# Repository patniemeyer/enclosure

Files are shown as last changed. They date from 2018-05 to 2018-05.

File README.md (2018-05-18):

# Simple OpenSCAD Press-fit Acrylic Printer Enclosure
_Pat Niemeyer (pat@pat.net), https://github.com/patniemeyer/enclosure_

<table>
  <tr>
    <th>
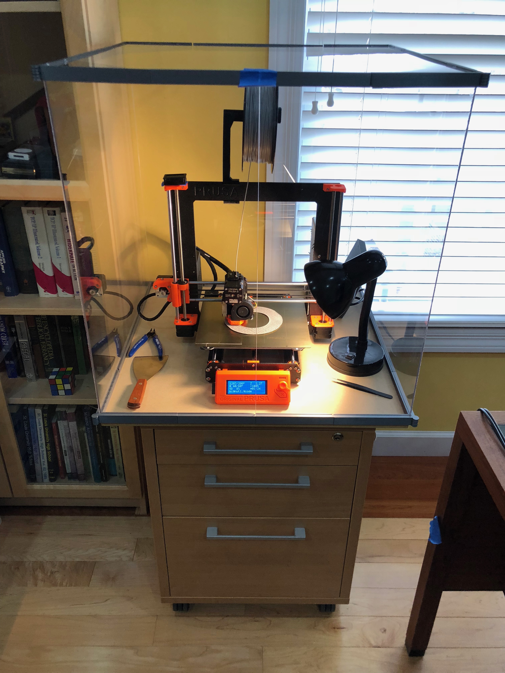
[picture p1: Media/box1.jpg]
      
    </th>
    <th>
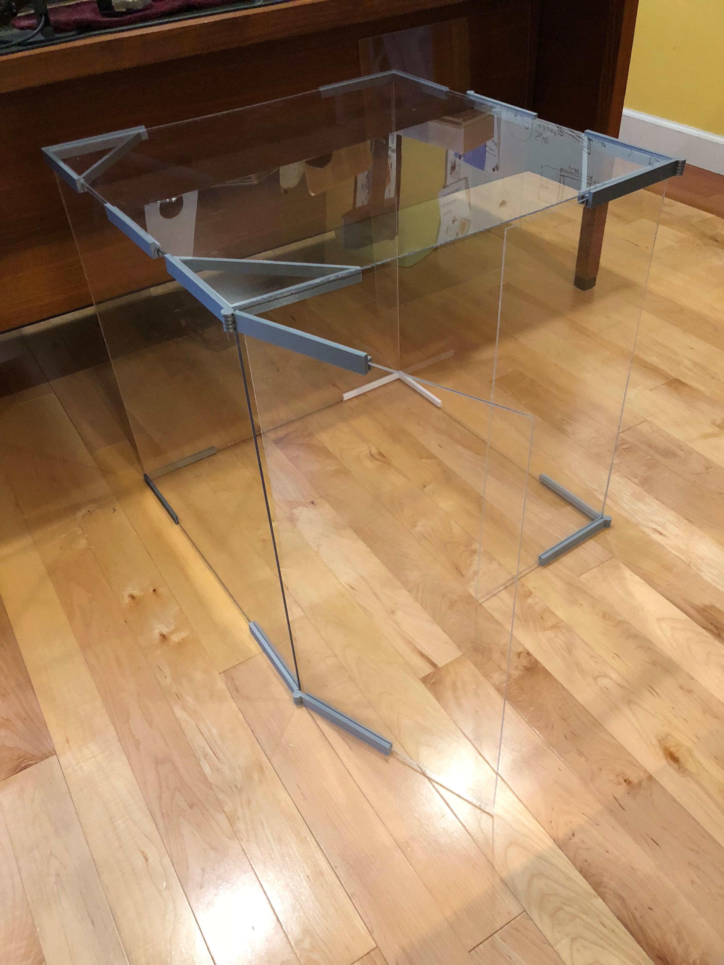
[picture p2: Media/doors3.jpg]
      
    </th>
    <th>
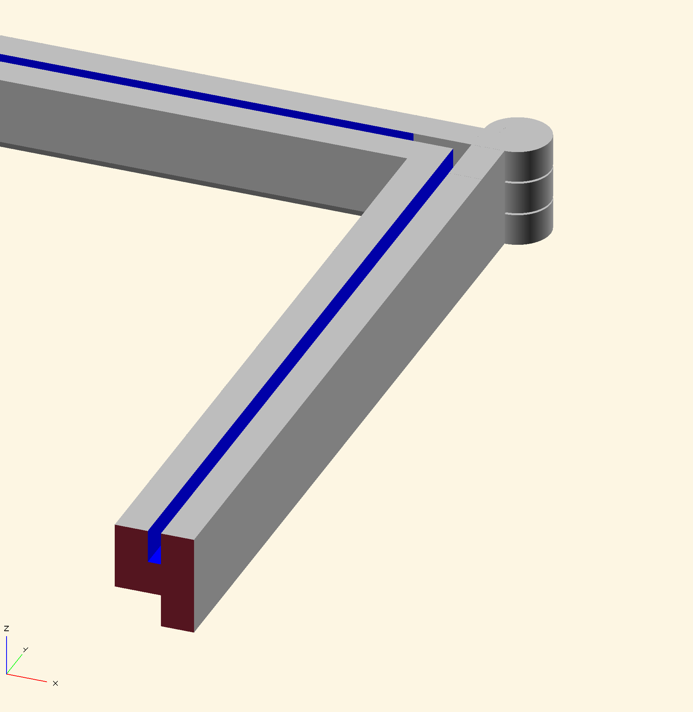
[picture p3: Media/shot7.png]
    
    </th>
  </tr>
</table>

This is my attempt at a simple, customizable press-fit printer enclosure that works with cheap (2.5mm or 3mm) acrylic and looks nice. The gihub project contains the OpenSCAD files that can be customized for any material thickness and box dimensions. Although I iterated on this a bit when I was building mine, I’d still consider this experimental so please read the notes below on what worked well and what didn’t.  I’m satisfied with the results and if I ever have another need for a giant acrylic box I’ll refine it more!

## Goals and room for improvement

* Use cheap acrylic:  1/4” acrylic is expensive.   You can get 3 sheets of 24x48” 3mm acrylic at Menard’s for less than $100 (you only really needed 2.5 of those for 5 panels). 

* Press-fit:  I did not want to have to drill or glue.  Other than getting 24” x 24” acrylic and cutting one in half for the doors I wanted to be able to press it together and perhaps take it apart when not needed.  In practice, the press-fit worked for some pieces but ended up a bit loose on others.  Ultimately I ended up putting a few spots of hot glue on strategic points to keep it from sliding.

* Base or no base:  The design incorporates a 24” x 24” base, but this can be removed (turned off in the scad file) for the bottom pieces if you prefer it to sit flush on a table.  Home Depot has 3/4” MDF square boards that are exactly 24” on a side for about $5. Sitting on a base allows the outside hinges to open the doors more freely.   If you use the base you may need to secure it since it doesn’t have much horizontal support in the front and could tend to slide off.

* Simple parts: Ideally it would use just three types of parts: straight edges, corner pieces, and hinged corner pieces.  In practice the thin acrylic slumped a bit on the “roof”, which made it harder to close the doors and in an attempt to fix this I adding the corner braces.  Unfotunately this means that there are now left and right hinges for the doors.   (Note: If you don’t care about the enclosure being air tight you don’t need the straight pieces!)

## Printing the parts 

The STL folder contains rendered models for a 24"x24" box with 0.118" / 3.0mm acrylic, but the scad files are easily adapted for any size and thickness.  If there is any interest in the project I will expand the pre-rendered selection and add instructions for options that can be customized. For now you'll just have to look at the source or ask me.

It does take a while to print the parts, but only the hinges require much detail.  I printed the straight and corner pieces at 0.2 or 0.35mm and the hinges at 0.1mm on my Prusa MK3.  The 12” straight pieces will fit if turned diagonally.

## Cutting Acrylic (if you have to) 
If you end up like me buying 48” sheets of acrylic you’ll need to cut them somehow.  I bought a 200 tooth table saw blade for $10 and it worked, but the results were a bit pitted.  Be sure to keep the plastic coating on the acrylic until you are finished cutting (or put blue painters tape on to protect if if you have exposed sheets).

## Ventilation 
I ended up placing mine on a table that it slightly smaller than the 24” base, allowing me to put a fan vent hole in the bottom.  In practice a 40mm fan can suck out enough air that it doesn’t really matter where it is.  I’m planning to vent it to a window later.

## Quiet!
Almost any kind of box that seals reasonbly well will dramatically reduce the sound of your printer- especially the high frequency whine of fans.  So yes, this does work well to reduce noise.

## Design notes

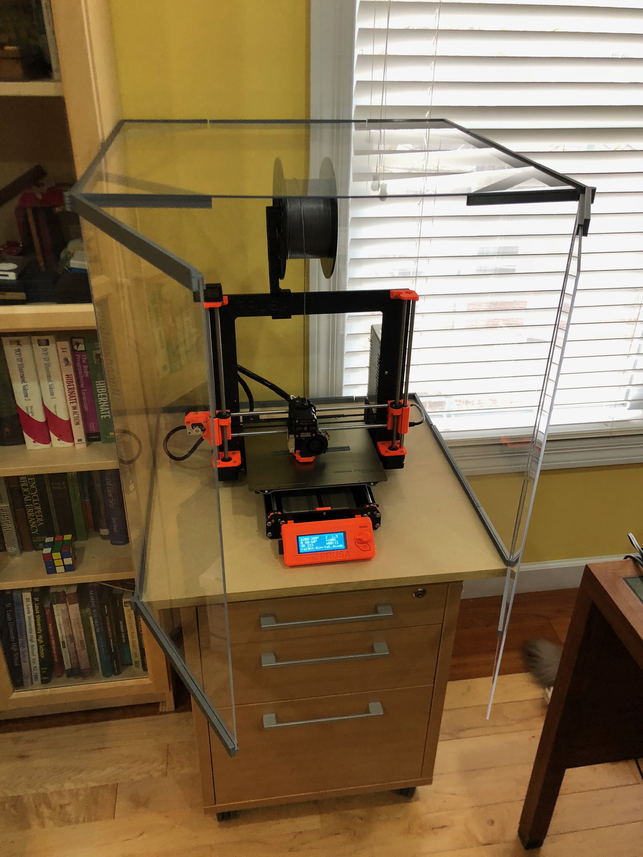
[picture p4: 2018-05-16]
Media/box2.jpg

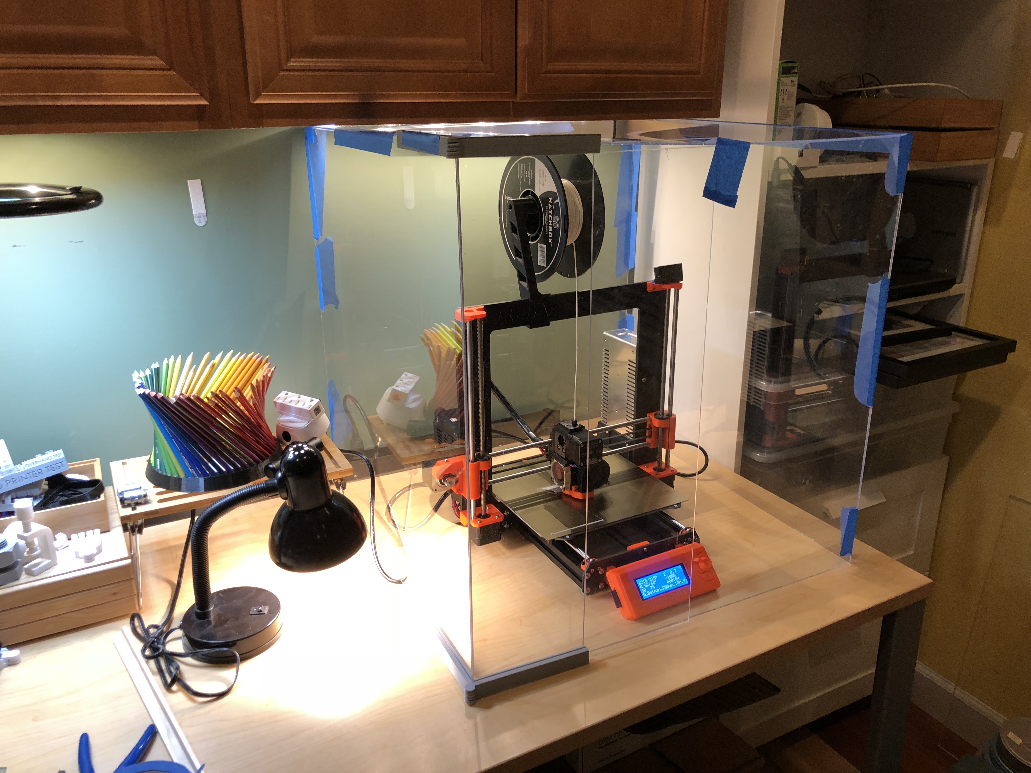
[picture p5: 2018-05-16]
Media/box3.jpg

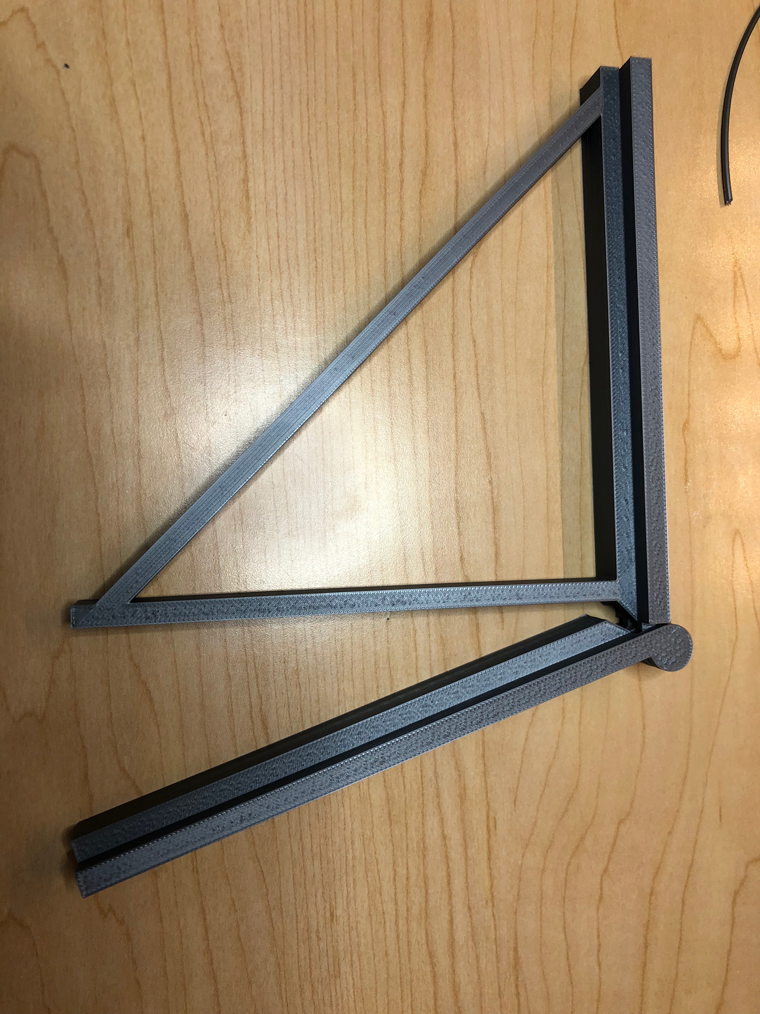
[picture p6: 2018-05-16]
Media/hinge3.jpg

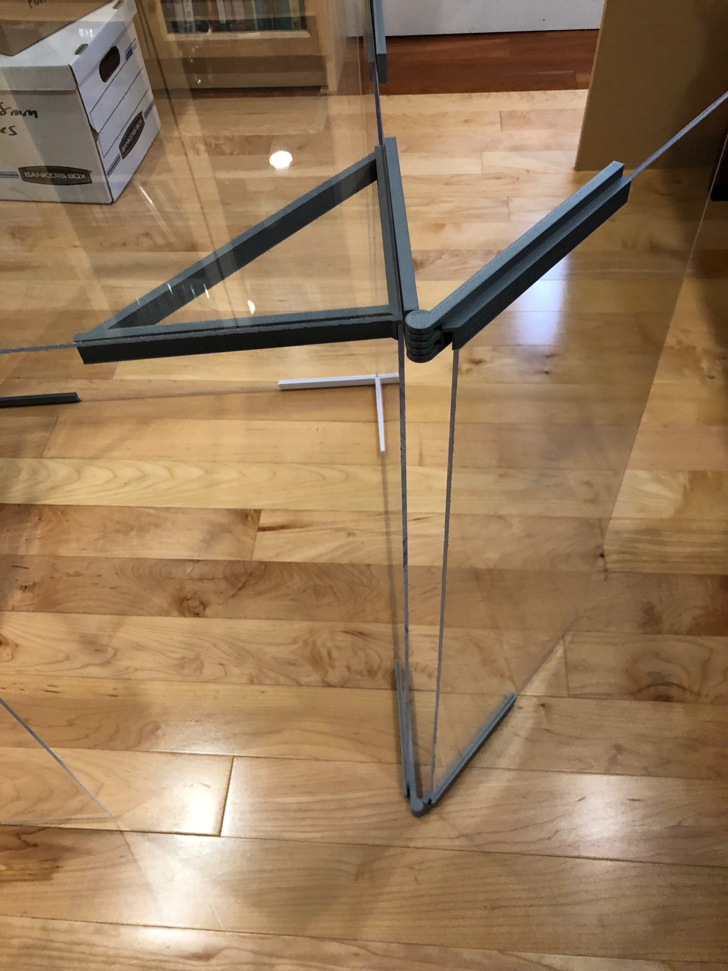
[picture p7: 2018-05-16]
Media/doors1.jpg

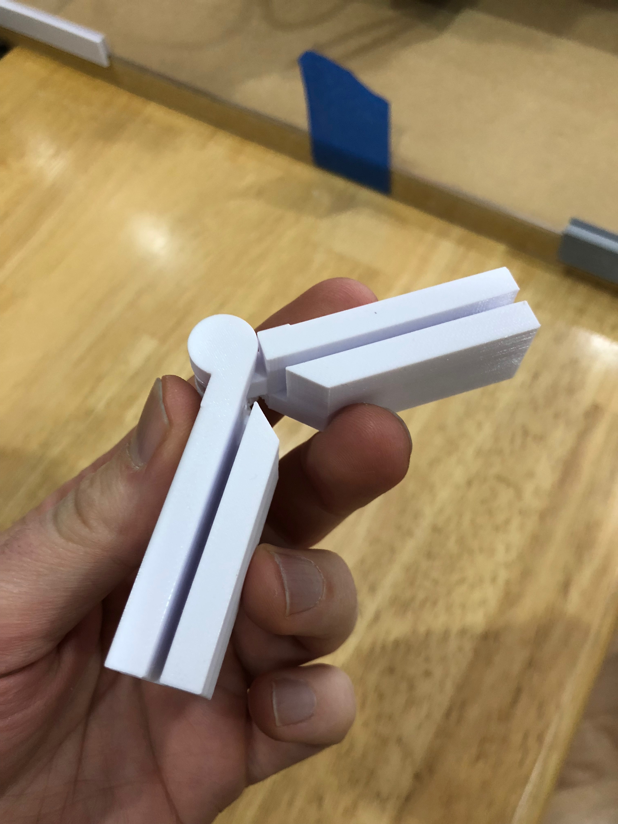
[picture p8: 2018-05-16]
Media/hinge2.jpg

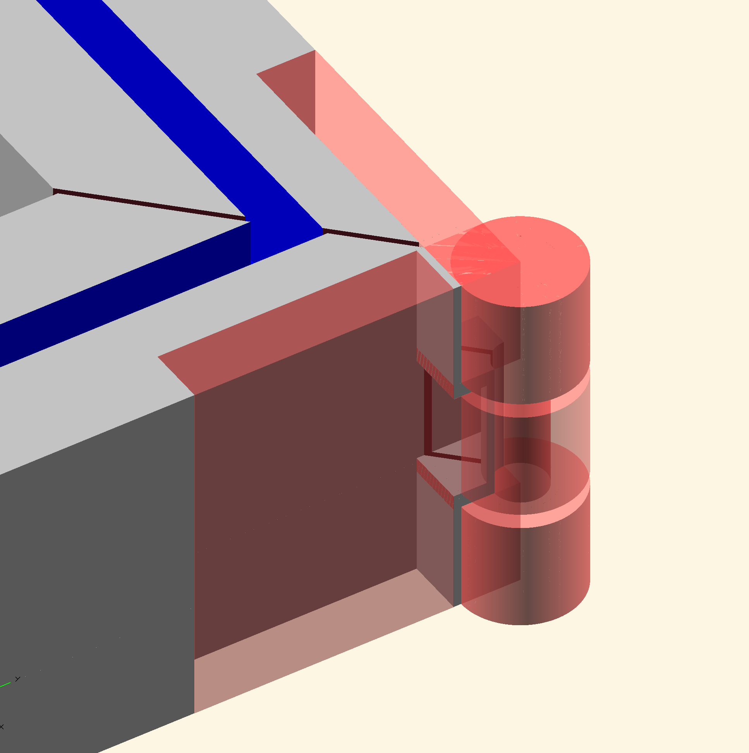
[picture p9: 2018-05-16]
Media/shot3.png

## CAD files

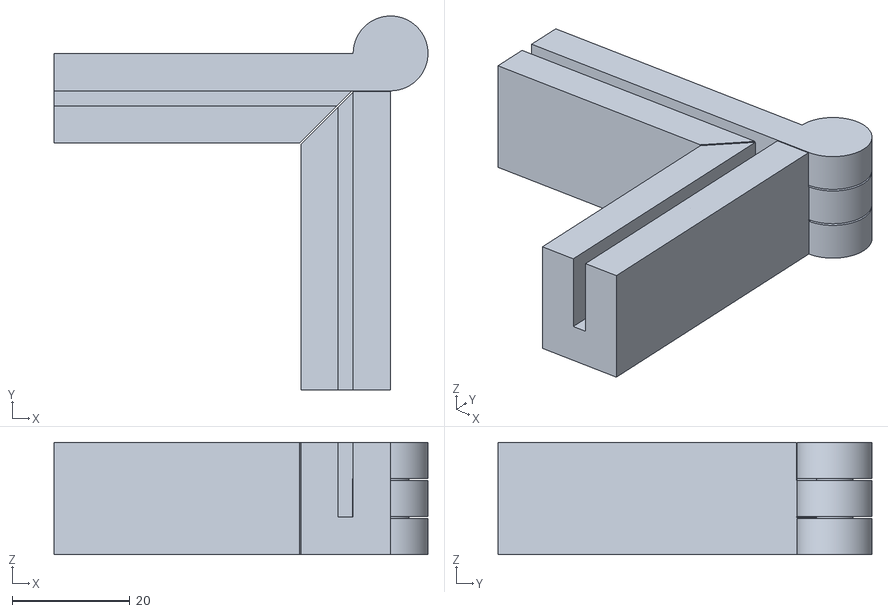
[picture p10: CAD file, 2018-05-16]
ExperimentsSTL/printer-enclosure6.stl
63.5 x 63.5 x 19.1

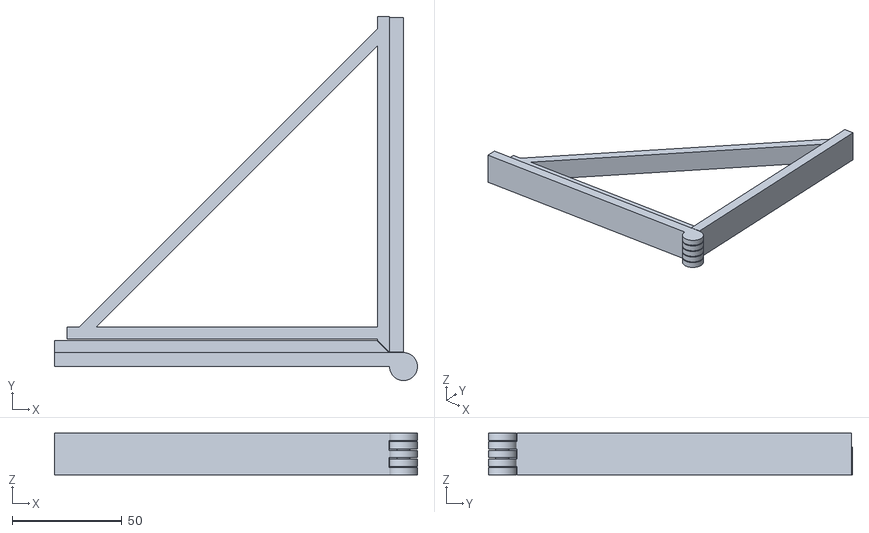
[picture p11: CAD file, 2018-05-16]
STL/corner-hinge-brace-right-6in.stl
165.1 x 165.6 x 19.1

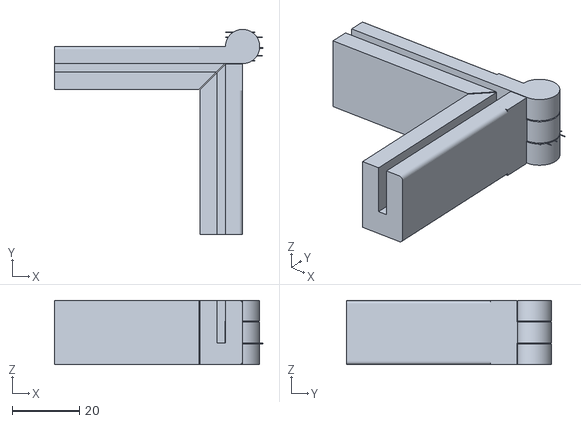
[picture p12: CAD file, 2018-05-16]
ExperimentsSTL/printer-enclosure10.stl
61.8 x 61.0 x 19.1

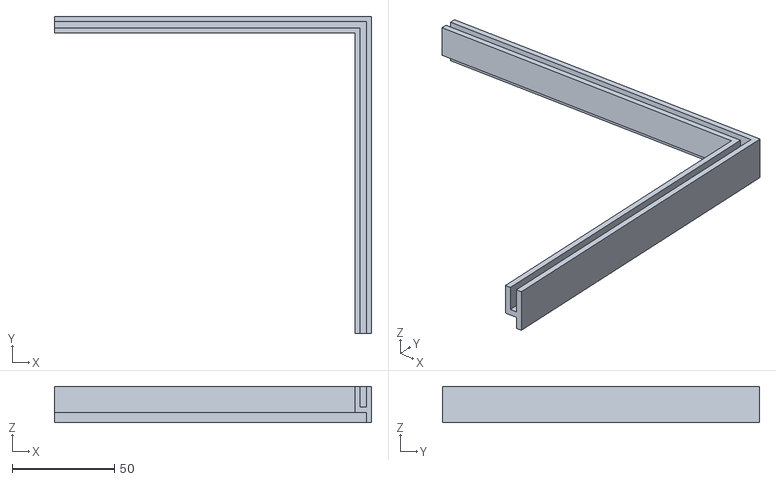
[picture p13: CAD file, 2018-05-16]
STL/corner-6in.stl
154.9 x 154.9 x 17.8

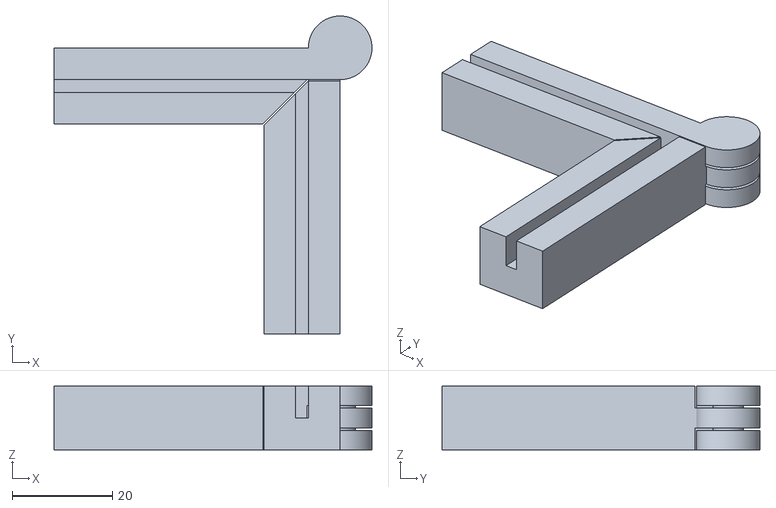
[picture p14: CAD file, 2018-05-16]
ExperimentsSTL/printer-enclosure.stl
63.5 x 63.5 x 12.7

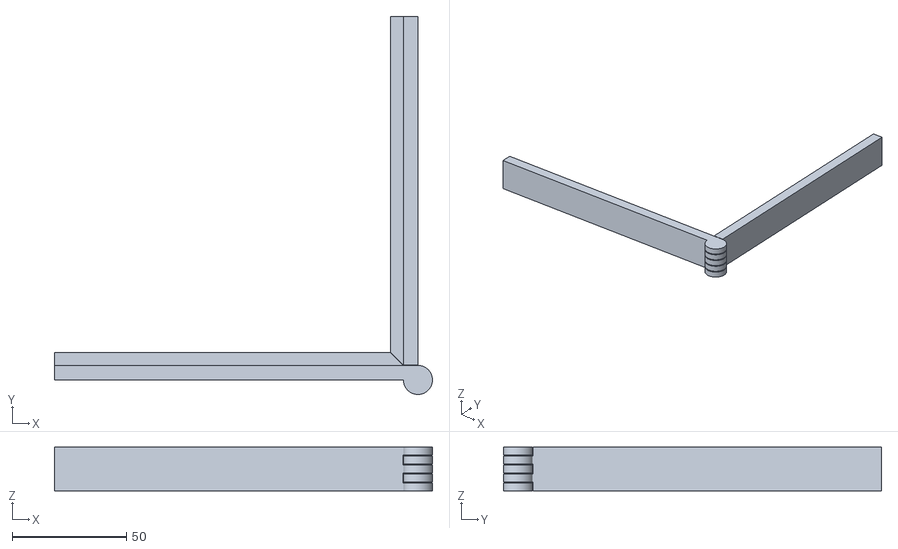
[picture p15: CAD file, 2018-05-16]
STL/corner-hinge-6in.stl
165.1 x 165.1 x 19.1

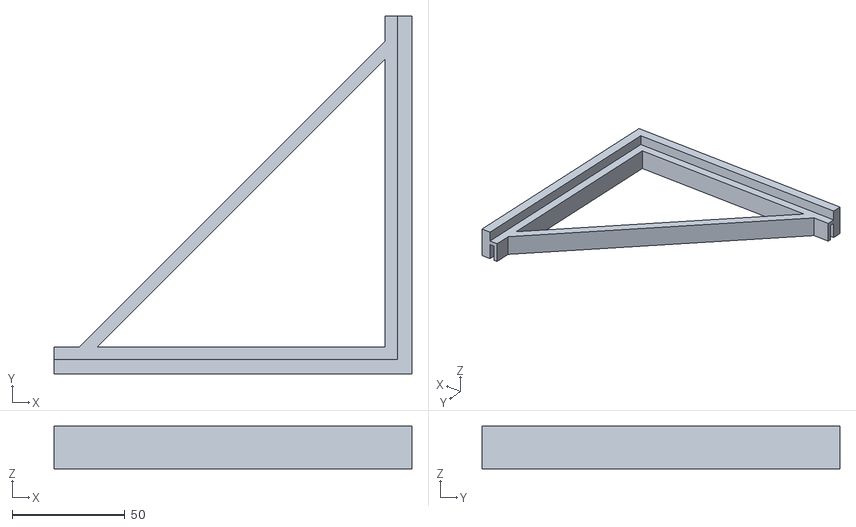
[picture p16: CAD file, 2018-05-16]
STL/corner-brace-6in.stl
158.8 x 158.8 x 19.0

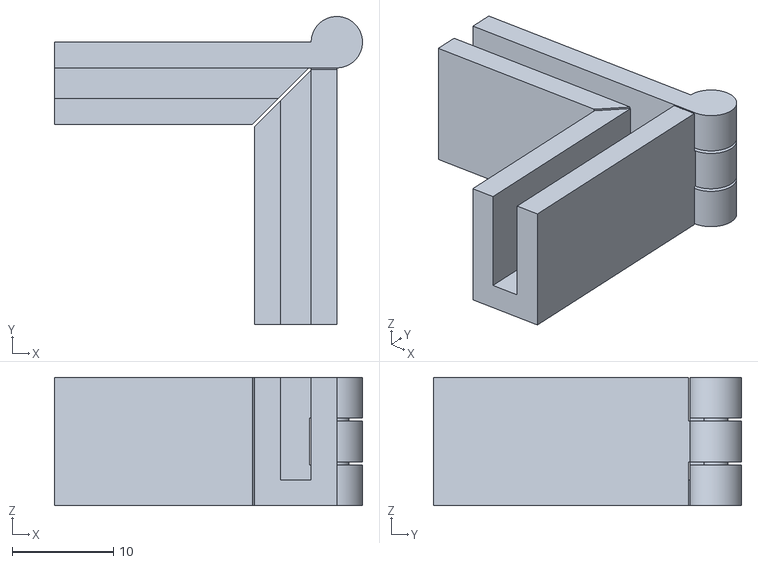
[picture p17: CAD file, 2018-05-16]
ExperimentsSTL/hingbottom1.stl
30.5 x 30.5 x 12.7

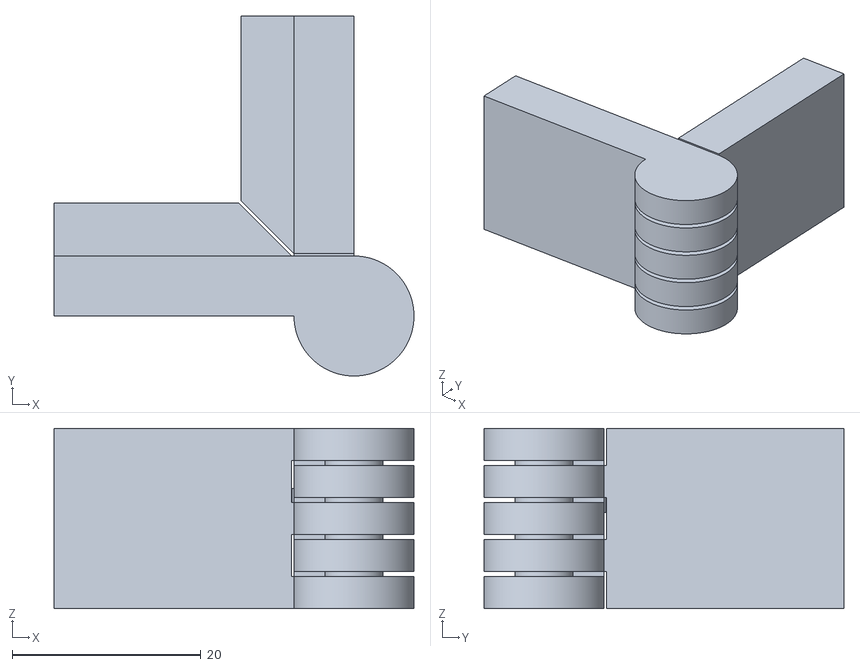
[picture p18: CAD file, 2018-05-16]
STL/corner-hinge-test-1in.stl
38.1 x 38.1 x 19.1

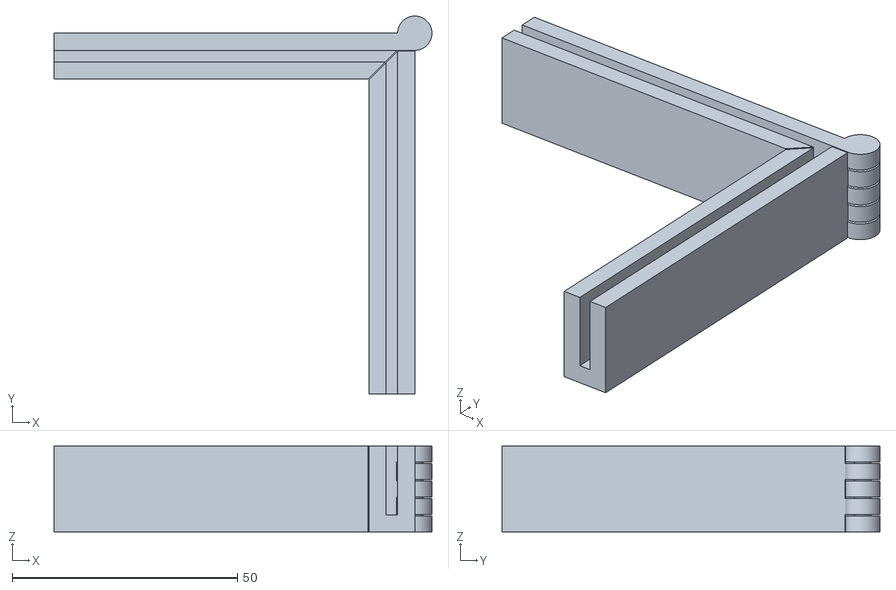
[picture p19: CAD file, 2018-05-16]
ExperimentsSTL/printer-enclosure18.stl
83.8 x 83.8 x 19.1

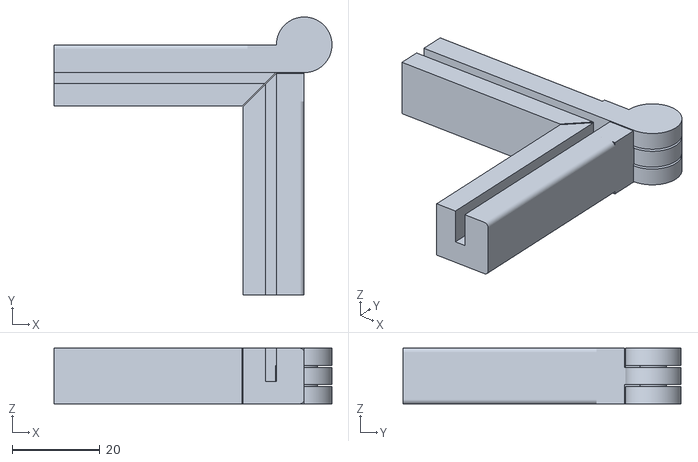
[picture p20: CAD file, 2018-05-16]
ExperimentsSTL/printer-enclosure15.stl
63.5 x 63.5 x 12.7

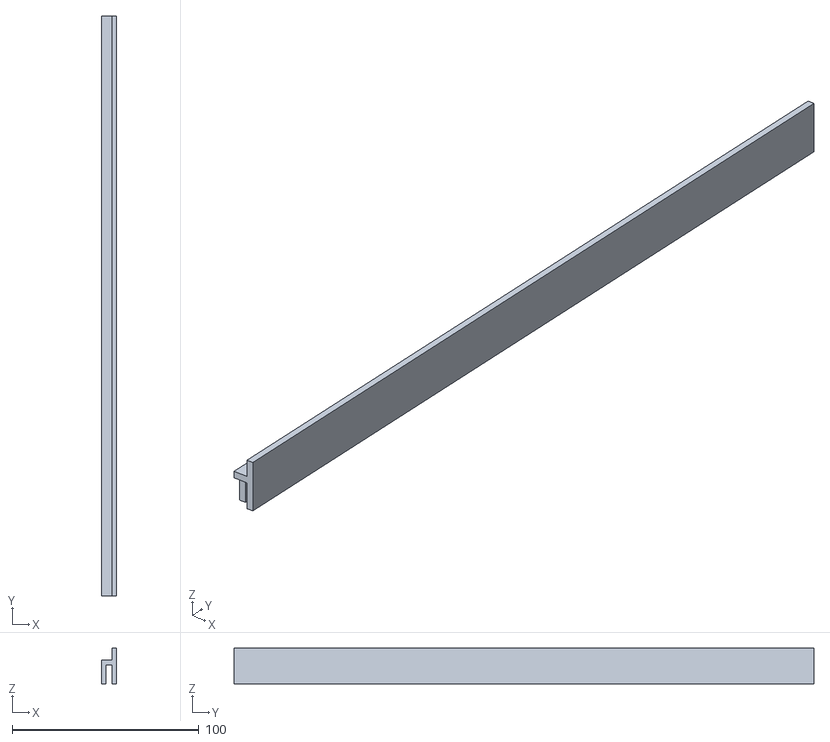
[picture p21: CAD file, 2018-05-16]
STL/straight-12in-thin.stl
8.13 x 310.9 x 19.0

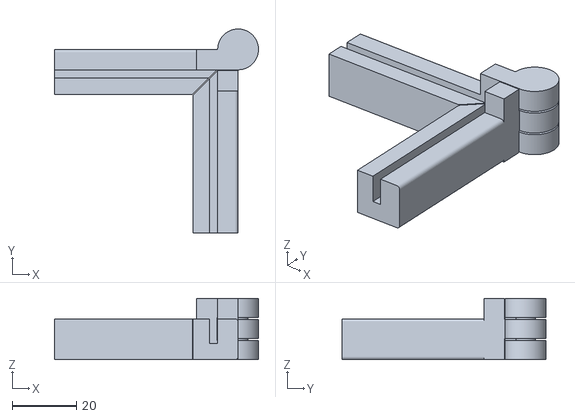
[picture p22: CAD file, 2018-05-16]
ExperimentsSTL/printer-enclosure13.stl
63.5 x 63.5 x 19.1

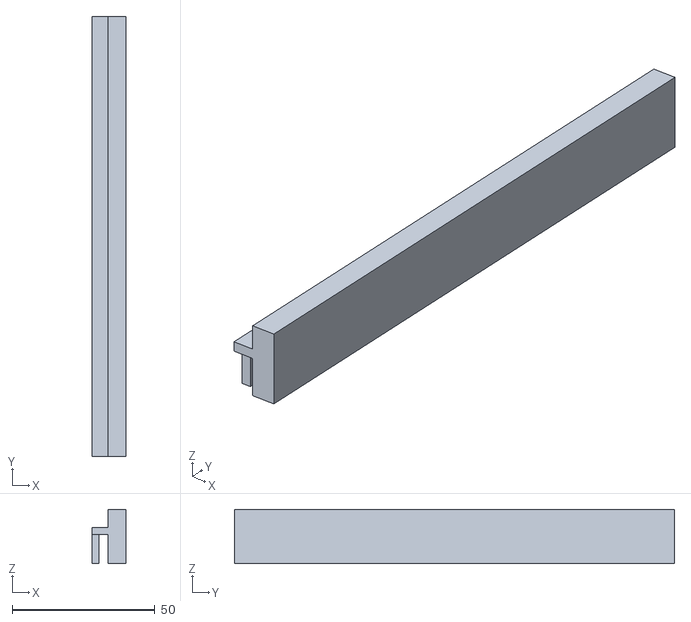
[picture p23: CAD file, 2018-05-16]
STL/straight-6in-fat.stl
11.9 x 153.9 x 19.0

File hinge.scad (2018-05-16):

// -------------------------------------+---------------------------------------+---------------------------------------+---------------------------------------
// Title:        Parametric Butt Hinge
// Version:      3.5.1
// Release Date: 2017-05-26 (ISO)
// Author:       Rohin Gosling
// -------------------------------------+---------------------------------------+---------------------------------------+---------------------------------------
//
// Description:
//
// - Parametric butt hinge, designed to be printed in one step.
//
// - While the entire working hinge may be printed in one step, it is also possible to disabled the internal fused pin, and leave a shaft
//   which may be used in the case where an external pin is desired.
//
// Release Notes:
//
// - Version 3.5
//   * For hexagonal counterbores, the hexagonal cut has been rotated 90 degrees, to reduce the need for support material.
//     The overhang angle for hexagonal counterbore is 60 degrees.
//
// - Version 3.4
//   * Added support for linear and parabolic gusset curves.
//   * Factored out all SCG (Solid Constructive Geometry) overlap constants, and consolidated them into one global constant, "SCG_OVERLAP".
//
// - Version 3.3
//   * Placed pin shaft parameters into their own parameter group in the Thingiverse Customizer.
//
// - Version 3.2
//   * Added support for independently configurable top and bottom pin shaft counterbores.
//   * Added an assembly option to flip the model about the z-axis. 
//     Usefull for viewing the top and bottom pin shaft counterbores.
//   * Configured the hinge throw angle Thingiverse Customizer parameter step size, to 5 degrees.
//
// - Version 3.1
//   * Added a counterbore feature for the pin shaft.
//     - While this feature may be enabled for one piece hinges that have the fused pin enabled, it is primarily designed for use with two
//       piece configurations that have their pin disabled. For instance, when the hinge is to be assembled using an external pin.
//     - In the case where a hinge is to be assembled using an external pin, it may be desired to have a pin shaft counterbore, where the end
//       caps of the knuckle joint array are counterbored, in order to allow the pin or bolt heads of the pin shaft, to be set flush with the
//       top and bottom edges of the hinge leaves.
//     - To accommodate both hexagonal and square bolt heads and nuts, the counterbore may be set to any one of circular, square or hexagonal.
//   * Added private text feature.
//     - A public parameter for the Thingiverse Customizer has not been added yet, however, users may set the 'text_enabled' local variable
//       in the 'leaf' module to 'true', which will enable a single row of inscribed text on each leaf.
//     - By default this feature will only work when exactly 4 fastener holes have been selected via the 'fastener_count' parameter, simply
//       because there is a nice open space available between the fastener holes for placing text, when 4 fastener holes are chosen.
//     - Text for the male and female leaves may be specified independently.
//
// - Version 3.0
//   * Added a parameter to disable the hinge pin, for when users would like to assemble with an external pin.
//   * Changed the main Thingiverse Customizer parameter group name from "Hinge Options", to "Assembly Options".
//   * Added a parameter to set the hinge throw angle.
//     Users can now set the throw angle, either for analysis and visualisation purposes, or for when the hinge is to be printed vertically
//     standing up on edge, in which case a throw angle of 120 degrees may be used to help keep the hinge stable on the build plate.
//   * Corrected spelling errors in the comments.
//
// - Version 2.9
//   * Added support for parabolic knuckle gussets to strengthen the knuckle joints.
//     Knuckle gussets may now be toggled on and off with the 'enable_knuckle_gusset' parameter.
//
// - Version 2.8
//   * Added the parameter, 'fastener_column_count', to enable single column fastener arrangements, that can be used for
//     piano hinge style fastener arrangements.
//
// - Version 2.7
//   * Rewrote the knuckle cutter module using mode generic math, that enables more parametizable control over knuckle joint 
//     dimensions and configuration.
//
// - Version 2.6
//   * Added support for countersunk fastener holes. Now users can select either counterbore or countersunk. 
//     dimensions and configuration.
//   * Started tracking release updates.
//
// - Version 1.0 - 2.5
//   * N/A - Release updates not tracked.
//
// -------------------------------------+---------------------------------------+---------------------------------------+---------------------------------------

// -------------------------------------+---------------------------------------+---------------------------------------+---------------------------------------
// Constants:
// -------------------------------------+---------------------------------------+---------------------------------------+---------------------------------------

// System constants.

C_CONSTANT = 0 + 0;     // Used to hide constant values from Thingiverse. Add to other constants to hide them as well.
C_NONE     = C_CONSTANT + 0;

// Leaf gender.

C_FEMALE   = C_CONSTANT + 0;
C_MALE     = C_CONSTANT + 1;

// SCG constants.

SCG_OVERLAP = C_CONSTANT + 0.01;    // Used for overlapping Boolean operations in order to avoid Boolean edge artefacts.
C_NEGATIVE  = C_CONSTANT + 0;       // Used for subtractive Boolean tools.
C_POSITIVE  = C_CONSTANT + 1;       // Used for additive Boolean tools.

// Bolt head shapes.

C_CIRCULAR  = C_CONSTANT + 0;
C_SQUARE    = C_CONSTANT + 1;
C_HEXAGONAL = C_CONSTANT + 2;

// Curve Type

C_FUNCTION_LINEAR    = C_CONSTANT + 1;      //  y = ax + b
C_FUNCTION_CIRCULAR  = C_CONSTANT + 2;      // r² = x² + y² 
C_FUNCTION_PARABOLIC = C_CONSTANT + 3;      //  y = a²(x - j)² + k    ...Vertex form.

// Minimum and maximum constraints.

C_MIN_HINGE_WIDTH                          = C_CONSTANT + 1.0;
C_MIN_HINGE_HEIGHT                         = C_CONSTANT + 1.0;
C_MIN_LEAF_GAUGE                           = C_CONSTANT + 1.0;
C_MIN_COMPONENT_CLEARENCE                  = C_CONSTANT + 0.1;
C_MAX_COMPONENT_CLEARENCE                  = C_CONSTANT + 1.0;
C_MIN_KNUCKLE_COUNT                        = C_CONSTANT + 3;
C_MAX_KNUCKLE_COUNT                        = C_CONSTANT + 15;
C_MIN_KNUCKLE_GUSSET_WIDTH                 = C_CONSTANT + 1.0; 
C_MIN_FASTENER_MARGIN                      = C_CONSTANT + 1.0; 
C_MIN_PIN_DIAMETER                         = C_CONSTANT + 1.0; 
C_MIN_COUNTER_SINK_DEPTH_STOP              = C_CONSTANT + 1.0; 
C_MIN_FASTENER_THREAD_DIAMETER             = C_CONSTANT + 0.0; 
C_MIN_FASTENER_COUNT                       = C_CONSTANT + 3; 
C_MIN_FASTENER_COLUMN_COUNT                = C_CONSTANT + 1; 
C_MAX_FASTENER_COLUMN_COUNT                = C_CONSTANT + 2; 
C_MIN_TESSELLATION                         = C_CONSTANT + 32; 
C_MAX_TESSELLATION                         = C_CONSTANT + 256;
C_MIN_THROW_ANGLE                          = C_CONSTANT + -90;
C_MAX_THROW_ANGLE                          = C_CONSTANT + 180;
C_DEFAULT_THROW_ANGLE                      = C_CONSTANT + 0;
C_MIN_PIN_SHAFT_COUNTERBORE_DIAMETER       = C_CONSTANT + 0.1;
C_MIN_PIN_SHAFT_COUNTERBORE_WALL_THICKNESS = C_CONSTANT + 0.3;
C_MIN_PIN_SHAFT_COUNTERBORE_DEPTH          = C_CONSTANT + 0.0;


// -------------------------------------+---------------------------------------+---------------------------------------+---------------------------------------
// Thingiverse Parameters.
//
// - These parameters are used to integrate with the Thingiverse Customizer, and should only be used by the
//   class member variables specified in the "Model parameters" section below.
//
// - These Thingiverse Parameters should never be accessed from inside any module. We do this to enforce 
//   principles of object orientation.
//
// - By separating concerns between variables exposed to Thingiverse vs. variables used internally by the 
//   SCAD model (class), we are better able to manage the ordering and grouping of variables exposed to 
//   Thingiverse, vs. the ordering of variables used internally by the model.
//
// -------------------------------------+---------------------------------------+---------------------------------------+---------------------------------------

/* [Assembly Options] */
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

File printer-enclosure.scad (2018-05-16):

///
///
/// OpenSCAD Press-fit Acrylic Printer Enclosure
/// By Pat Niemeyer (pat@pat.net) 
/// https://github.com/patniemeyer/enclosure
///
/// This code is messy. If there is any interest in it going forward I'll clean it up!
/// While I did end up with a decent result this could be improved a lot.  Please see the README.md
/// for notes on what worked well and what didn't.
///

include <rounded.scad>;

$fn=50;
O=0.01;  // Negligable offset
OT=0.02; // Negligable offset for thickness

s=24*25.4; //size of the base
sh=1*25.4; // height of the base
mt=0.12*25.4; // material thickness

goho=0.25*25.4; // guide overlap horizontal outside (starting outside the material)
//goho=0.10*25.4; // guide overlap horizontal outside (starting outside the material)
gohi=0.10*25.4; // guide overlap horizontal inside (starting inside the material)

gova=0.5*25.4; // guide overlap vertical above 
govb=0.25*25.4; // guide overlap vertical below (the lip that hangs down over the base)
//govb=0;

gbh=0.10*25.4; // guide bottom height (the glass sits on this)

// Cut out one corner
cutaway=6.0*25.4*1.01;
cutawayx=-cutaway; // remaining section size
cutawayy=-cutaway; // remaining section size

// Corner support
corner_brace_len = -cutawayx;
corner_brace_width = gohi+mt;
corner_brace_height = gova;

rounding=0;

// Hinge param
knuckle_count = 5;               // [3:2:31]
leaf_gauge = goho;
hinge_width  = 56.0;

leaf_height = gova+govb+0.004;
//leaf_height = 0.75*25.4;

component_clearance = 0.5;
throw_angle = -90.0;   // [ -90 : 5 : 180 ]
knuckle_gusset_type = 0;     // [ 0:None, 1:Linear, 2:Circular, 3:Parabolic ]

module base() {
  color("gray")
  cube([s,s,sh], center=true);
}

module glass() {
  color("blue")
  translate([0,0,s/2+sh/2+gbh])
  difference() {
    cube([s,s,s], center=true);
    cube([s-2*mt,s-2*mt,s+.01], center=true);
  }
}

module guide() 
{
  color("silver")
  translate([0,0,sh/2])
  difference() {
    // exterior
    os=s+2*goho;
    union() {
      // above
      translate([0,0,gova/2])
      roundedCube([os,os,gova], rounding, center=true);
      // below
      translate([0,0,-govb/2+rounding])
      roundedCube([os,os,govb+2*rounding], rounding, center=true);
    }

    // remove interior, material inside the edge and inside the interior overhang
    is=s-2*gohi-2*mt;
    cube([is,is,10*25.4], center=true);

    // remove material channel
    glass();
  }
}

module cutaway(x,y) {
  translate([x,0,0])
  cube([s,s*3,3*s], center=true);
  translate([0,y,0])
  cube([s*3,s,3*s], center=true);
}

// show the base
*%difference() {
    base();
    cutaway(cutawayx, cutawayy);
}

//  Show the glass
*difference() {
  glass(); 
  cutaway(cutawayx, cutawayy);
}

module hingeSlice() {
  sliceThickness=0.3;
  rotate([0,0,45])
  translate([0,/*-100*/,0])
  cube([s*2,sliceThickness/*+200*/,3*25.4], center=true);
}

module guideHinge(
  enable_male_leaf             = 1,     // [ 0:No, 1:Yes ]
  enable_female_leaf           = 1,     // [ 0:No, 1:Yes ]
  hinge_outsety = 0,
  hinge_outsetx = 0,
  scalexy=1.0, scalez=1.0
) 
{
  include <hinge.scad>;

  translate([s/2+goho+hinge_outsetx, s/2+goho+hinge_outsety, sh/2+leaf_height/2-govb])
  rotate([90,0,90])
  //color("red")
  scale([scalexy,scalez,scalexy]) 
  hinge();
}

// The corner area to be occupied by the hinge, removed so that the hinge doesn't internally intersect with it.
module cornerCutout(clearance=component_clearance) 
{
  cw=goho+clearance;
  translate([s/2-cw+goho-O, s/2-O, sh/2-govb-O])
  cube([cw*2+OT, goho*2+OT, gova+govb+OT]);

  translate([s/2+goho*2+O, s/2-cw+goho+O, sh/2-govb-O])
  rotate([0,0,90])
  cube([cw*2+OT, goho*2+OT, gova+govb+OT]);
}

// TODO:
BRACE_NONE=0;
BRACE_LEFT=1;
BRACE_RIGHT=2;
BRACE_BOTH=3;

module cornerBrace(left=true) 
{
  interior=mt+gohi;
  cbl = corner_brace_len;
  cbw = corner_brace_width;
  cbh = corner_brace_height;

  // brace left or right
  //xoff = left ? -component_clearance : cbw;
  //yoff = left ? cbw : -component_clearance;

  // brace both
  xoff = cbw;
  yoff = cbw;

  translate([xoff, yoff, 0])
  intersection() 
  {
    union() 
    {
      // side left
      translate([s/2-cbw-interior, s/2-cbl, gova])
      cube([cbw, cbl-interior, cbh], center=false);

      // side top
      translate([s/2-interior, s/2-cbw-interior, gova])
      rotate([0,0,90.0])
      cube([cbw, cbl-interior, cbh], center=false);

      // diagonal
      translate([s/2-interior, s/2-cbl, gova])
      rotate([0,0,45.0])
      translate([0, -cbl/3, 0]) // slide along diagonal
      cube([cbw, cbl*2, cbh], center=false);
    }

    // interior space
    translate([s/2-cbl, s/2-cbl, gova])
    cube([cbl-interior, cbl-interior, cbh], center=false);
  }
}

module cornerElement() {
  difference() {
    guide();
    base();
    glass(); 
    cutaway(cutawayx, cutawayy);
  }
}

// A corner with optional hinge and brace
module corner(hinge=true, brace=BRACE_LEFT) {
  // The guide
  difference() {
    //guide();
    //base();
    //glass(); 
    //cutaway(cutawayx, cutawayy);
    cornerElement();

    if (hinge) {
      hingeSlice();
      cornerCutout();
    }
  }
  // The hinge
  if (hinge) {
    //intersection() {
      guideHinge();
      //cornerCutout();
    //}
  }
  // TODO: use brace selector
  // Add the corner brace
  if (brace != BRACE_NONE) {
    difference() {
      color("gray")
      cornerBrace();
      glass();
    }
  }
}

module straight() {
  difference() {
    cornerElement();

    // Cut off the end. 
    // TODO: leaves a gap at the corner.
    translate([goho+O, s/2-O, 0])
    cube([s/2, s/2, 50], center=false);
    translate([-mt-gohi-s/2, s/2-mt-gohi-O, 0])
    cube([s, s/2, 50], center=false);
  }
}

// 
// Uncomment to generate the part you want
//
rotate([180,0,0])
translate([-s/2, -s/2, 0]) // center it in the workspace
echo("Rendering a left side hinge");
corner(hinge=true, brace=BRACE_LEFT);
//corner(hinge=false, brace=BRACE_BOTH);
//corner(hinge=true, brace=BRACE_NONE);
//straight();

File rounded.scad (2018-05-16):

// Rounded box: radius is added outside, to each dimension
module roundedCube(size/*[x,y,z]*/, radius, center=true)
{
    width = size[0] - radius*2;
    length = size[1] - radius*2;
    height = size[2] - radius*2;

    minkowski() {
        cube(size=[width,length,height], center=center);
        sphere(r=radius, center=center);
    }
}

// A rounded rect fitting exactly width and length taking into account the radius.
// At r=w/2, r=l/2 this this is circular.
// See roundedCube for a box with corners rounded in 3 dimensions.
// size - [width,length,height]
// radius - radius of corners
//
// TODO: Would be nice to be able to control the z-dimension radius separately for making shallow rounded things.
//
module roundedRect(size, radius)
{
	x = size[0]-r;
	y = size[1]-r;
	z = size[2];

	linear_extrude(height=z)
	hull()
	{
		// place 4 circles in the corners, with the given radius
		translate([(-x/2)+(radius/2), (-y/2)+(radius/2), 0])
		circle(r=radius);
	
		translate([(x/2)-(radius/2), (-y/2)+(radius/2), 0])
		circle(r=radius);
	
		translate([(-x/2)+(radius/2), (y/2)-(radius/2), 0])
		circle(r=radius);
	
		translate([(x/2)-(radius/2), (y/2)-(radius/2), 0])
		circle(r=radius);
	}
}

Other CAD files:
ExperimentsSTL/printer-enclosure9.stl
STL/corner-hinge-brace-left-6in.stl
ExperimentsSTL/printer-enclosure17.stl
ExperimentsSTL/corner1.stl
ExperimentsSTL/hingetop1.stl
ExperimentsSTL/printer-enclosure12.stl
ExperimentsSTL/printer-enclosure16.stl
ExperimentsSTL/printer-enclosure2.stl
ExperimentsSTL/printer-enclosure4.stl
ExperimentsSTL/printer-enclosure7.stl
ExperimentsSTL/printer-enclosure8.stl
